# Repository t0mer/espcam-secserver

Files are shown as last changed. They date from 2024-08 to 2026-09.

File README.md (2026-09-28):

# ESP32-CAM Security Server




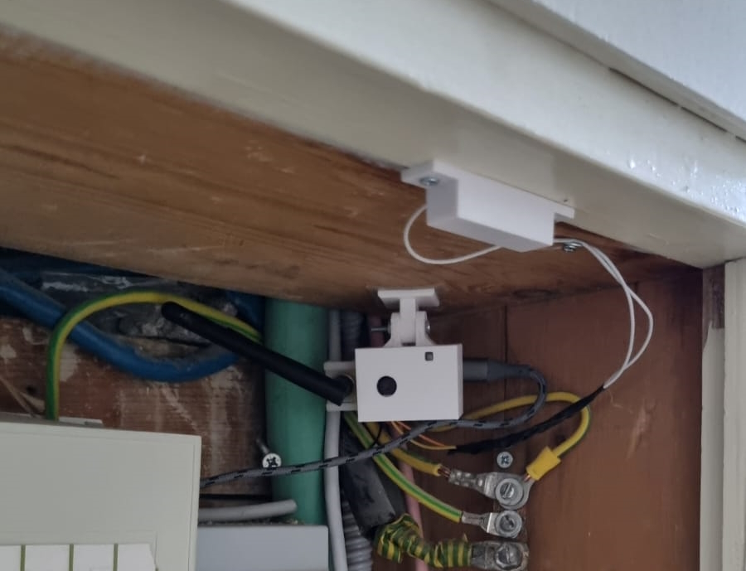
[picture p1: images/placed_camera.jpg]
Camera setup


## Overview

`espcam-secserver` is a DIY door security camera built from an ESP32-CAM and a small Python backend.
When a door magnet (reed switch) wired to the ESP32-CAM detects that the door opened, the camera
turns on its flash LED and calls the backend. The **FastAPI** backend then pulls three snapshots
from the camera, one second apart, and sends them to a WhatsApp contact or group through
[Green API](https://green-api.com/en).

The repository contains:

- `app/` - the FastAPI backend (runs in Docker).
- `CameraWebServer/` - the ESP32-CAM Arduino sketch (based on the Espressif `CameraWebServer`
  example, extended with the door sensor and backend trigger).
- `esp-32-cam-case-model_files/` - 3D-printable case files.
- `sequence-diagram/` - the flow diagram shown below.

## Table of Contents

- [Features](#features)
- [How it works](#how-it-works)
- [Hardware](#hardware)
- [Firmware setup](#firmware-setup)
- [Backend installation](#backend-installation)
- [Configuration](#configuration)
- [Green API setup](#green-api-setup)
- [API reference](#api-reference)
- [Security notes](#security-notes)
- [Troubleshooting](#troubleshooting)
- [Development](#development)
- [Contributing](#contributing)
- [License](#license)

## Features

- **Door-triggered capture**: a reed switch on GPIO 13 of the ESP32-CAM triggers the capture when
  the door opens.
- **Flash LED**: the on-board flash LED (GPIO 4) turns on when the door opens and turns off
  4 seconds after the door opens (or when the door closes), but not before the backend request
  returns, which can take up to `backendTimeoutMs` (10 s).
- **Three snapshots per event**: the backend fetches `/capture` from the camera three times,
  one second apart.
- **WhatsApp notifications**: each snapshot is uploaded and sent to a contact or group via
  [Green API](https://green-api.com/en), with an optional caption.
- **Multiple cameras**: the backend uses the caller's IP address as the camera address, so any
  number of cameras can share one backend.
- **Shared-secret authentication**: the trigger endpoint requires an `AUTH_TOKEN`, compared in
  constant time. The server refuses to start without it.
- **SSRF protection**: the backend only fetches images from callers on a private or loopback
  network.
- **Credential redaction**: the Green API token, instance ID and auth token are scrubbed from the
  application's log messages (Uvicorn's access log is not redacted).
- **Docker support**: slim Python 3.12 image, non-root user, built-in healthcheck on `/health`.
- **3D-printable case**: STL files for a wall-mounted case.

## How it works

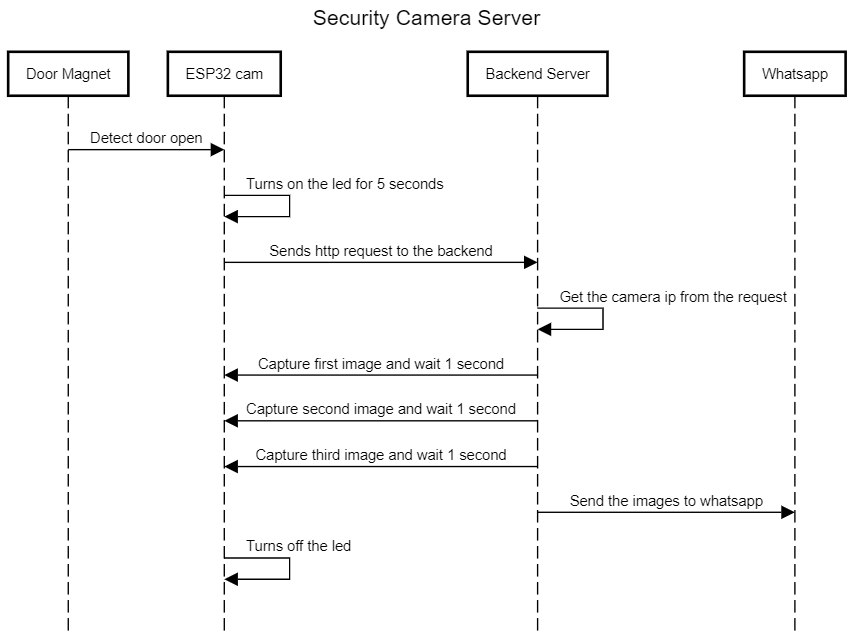
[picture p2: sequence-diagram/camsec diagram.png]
Sequence diagram


1. The door magnet opens and GPIO 13 on the ESP32-CAM reads `HIGH`.
2. The ESP32-CAM turns on the flash LED and sends `GET <backendUrl>` with an `X-Auth-Token` header.
3. The backend checks the token and takes the camera IP address from the request's source address.
4. The backend fetches `http://<camera-ip>/capture` three times, waiting one second after each.
5. Each captured image is uploaded to Green API and sent to `TARGET` with the `MESSAGE` caption.
6. The LED turns off 4 seconds after the door opens, or when the door closes, but only once the
   backend request has returned (the request blocks the firmware loop).

The diagram source is in [`sequence-diagram/camsec diagram.txt`](sequence-diagram/camsec%20diagram.txt)
(sequencediagram.org syntax). Note that it says the LED stays on for 5 seconds; the firmware uses
4 seconds (`ledDuration = 4000`).

## Hardware

- **ESP32-CAM, AI Thinker model** (the sketch selects `CAMERA_MODEL_AI_THINKER`; other boards are
  defined in `camera_pins.h` but require changing the `#define`).
- **USB-to-serial adapter** (FTDI or similar) to flash the ESP32-CAM, unless your board has a USB
  programmer base.
- **Door magnet / reed switch** between **GPIO 13** and **GND**. The pin uses the internal pull-up,
  so it reads `LOW` while the magnet holds the switch closed and `HIGH` when the door opens.
- **5 V power supply** for the ESP32-CAM.

### Case

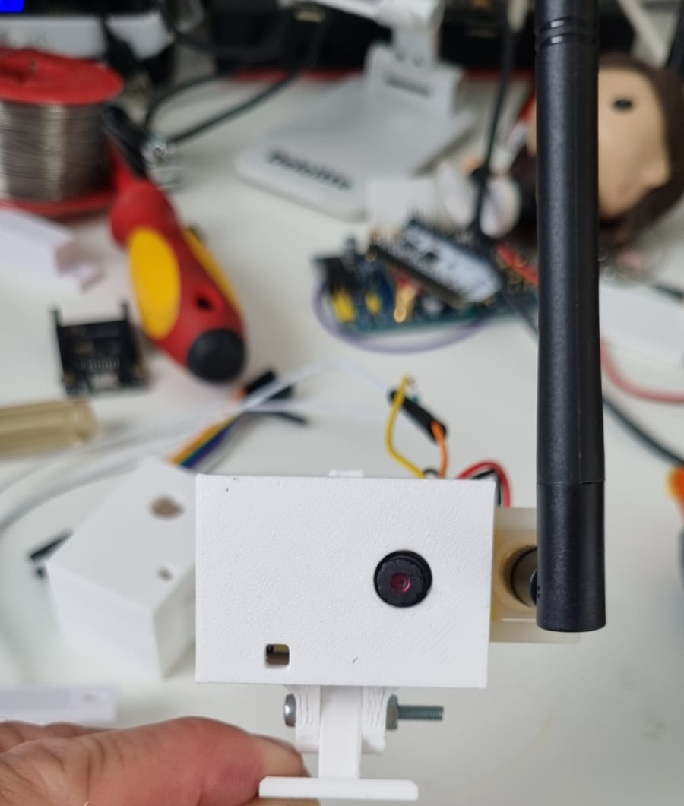
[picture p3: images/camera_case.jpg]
Camera case


The case is the [ESP 32 Cam Case](https://www.printables.com/model/30066-esp-32-cam-case) by
Fabian on Printables, released into the public domain. The files are in
[`esp-32-cam-case-model_files/`](esp-32-cam-case-model_files):

| File | Part |
|---|---|
| `gehause.stl` | Housing |
| `deckel.stl` | Lid |
| `fuss.stl` | Wall mount (foot) |

The model's print sheet (the PDF in the same folder) lists PLA, 0.20 mm layers, a 0.40 mm nozzle,
about 22 g of filament and about 2 hours on a Prusa MINI.

## Firmware setup

1. Install the [Arduino IDE](https://www.arduino.cc/en/software) and the **esp32** board package
   by Espressif (Boards Manager).
2. Open `CameraWebServer/CameraWebServer.ino`.
3. Edit the settings at the top of the sketch:

   | Setting | Description |
   |---------|-------------|
   | `ssid` / `password` | Your Wi-Fi network credentials. |
   | `backendUrl` | Base URL of the backend, including scheme, host and port, for example `http://192.168.1.100:8000/`. With the provided `docker-compose.yaml`, the host port is `80`. |
   | `authToken` | Must match the backend's `AUTH_TOKEN`. |
   | `backendTimeoutMs` | Timeout for the trigger request (default `10000` ms). |
   | `doorPin` | Reed switch GPIO (default `13`). |
   | `ledPin` | Flash LED GPIO (default `4`). |
   | `ledDuration` | Minimum time the LED stays on (default `4000` ms); it stays on until the backend request returns. |

4. Select the **AI Thinker ESP32-CAM** board and the serial port. The sketch folder contains a
   custom `partitions.csv`, which the esp32 Arduino core uses automatically.
5. Put the board in flashing mode (GPIO 0 to GND on most boards), upload, then remove the jumper
   and reset.
6. Open the Serial Monitor at **115200** baud. After connecting, the board prints its address
   (`Camera Ready! Use 'http://<ip>' to connect`).

The camera must be on the same private network as the backend. A DHCP reservation for the camera
is not required: the backend reads the camera IP from each request.

The firmware keeps the standard `CameraWebServer` web interface: the control page and `/capture`
on port 80, and the MJPEG stream on port 81 (`/stream`).

## Backend installation

> **Note:** the image on Docker Hub (`techblog/espcam-secserver:latest` and `:0.0.1`) was published
> in August 2024 and predates the current source (for example `AUTH_TOKEN`, `/health` and the
> non-root user). Until a new image is published, build the image locally as shown below.

### Docker Compose (recommended)

```bash
git clone https://github.com/t0mer/espcam-secserver.git
cd espcam-secserver
docker build -t techblog/espcam-secserver .
```

Fill in the environment variables in `docker-compose.yaml`:

```yaml
services:
  espcam-secserver:
    image: techblog/espcam-secserver
    container_name: espcam-secserver
    restart: always
    environment:
      - GREEN_API_INSTANCE_ID= #Green API Instance Id
      - GREEN_API_TOKEN= #Green API Token
      - TARGET= #Target phone number 972*********@c.us for contact or @g.us for group
      - MESSAGE= #Caption for the image sent
      - AUTH_TOKEN= #Shared secret required to trigger the capture endpoint
      - CORS_ORIGINS= #Optional comma-separated allowed CORS origins
    ports:
      - "80:8000"
```

Then start it:

```bash
docker compose up -d
```

The container listens on port `8000`; the compose file publishes it on host port `80`.

### Docker

```bash
docker run -d --name espcam-secserver --restart always \
  -p 8000:8000 \
  -e GREEN_API_INSTANCE_ID=<instance-id> \
  -e GREEN_API_TOKEN=<token> \
  -e TARGET=972XXXXXXXXX@c.us \
  -e MESSAGE="Door opened" \
  -e AUTH_TOKEN=<shared-secret> \
  techblog/espcam-secserver
```

### Run without Docker

```bash
pip install -r requirements.txt
export GREEN_API_INSTANCE_ID=... GREEN_API_TOKEN=... TARGET=... AUTH_TOKEN=...
python3 app/app.py
```

The Docker image uses Python 3.12.

## Configuration

All configuration is done with environment variables.

| Variable | Required | Default | Description |
|---|---|---|---|
| `GREEN_API_INSTANCE_ID` | Yes | - | Green API instance ID. |
| `GREEN_API_TOKEN` | Yes | - | Green API instance token. |
| `TARGET` | Yes | - | WhatsApp chat ID to send the images to: `<phone>@c.us` for a contact (international format, digits only, for example `972501234567@c.us`) or `<id>@g.us` for a group. The value is used as-is, so include the suffix. |
| `AUTH_TOKEN` | Yes | - | Shared secret the camera must send to trigger a capture. Must match `authToken` in the firmware. |
| `MESSAGE` | No | none | Caption sent with each image. |
| `CORS_ORIGINS` | No | empty (no cross-origin access) | Comma-separated list of allowed CORS origins (`GET` only, no credentials). |
| `REQUEST_TIMEOUT` | No | `10` | Timeout in seconds for each image request to the camera. |
| `PORT` | No | `8000` | Port the server listens on. Keep it at `8000` in Docker: the image's `EXPOSE`, `HEALTHCHECK` and the compose port mapping all use 8000. |

The server exits at startup with `Missing required environment variables: ...` if any required
variable is empty.

## Green API setup

1. Create an account at [green-api.com](https://green-api.com/en) and create an instance.
2. Link the instance to a WhatsApp account by scanning the QR code in the Green API console.
3. Copy the **idInstance** into `GREEN_API_INSTANCE_ID` and the **apiTokenInstance** into
   `GREEN_API_TOKEN`.
4. Set `TARGET` to the chat that should receive the images (see the table above).

The backend uses the [`whatsapp-api-client-python`](https://pypi.org/project/whatsapp-api-client-python/)
SDK: it uploads each image with `uploadFile` and sends it with `sendFileByUrl`.

## API reference

FastAPI also serves interactive documentation at `/docs` (Swagger UI) and `/redoc`, and the
schema at `/openapi.json`.

### `GET /` - trigger a capture

Called by the ESP32-CAM when the door opens.

Authentication: the `X-Auth-Token` header, or the `token` query parameter, must equal `AUTH_TOKEN`.

```bash
curl -H "X-Auth-Token: <shared-secret>" http://<backend>:8000/
```

The request must come from the camera itself: the backend fetches images from
`http://<caller-ip>/capture`.

| Status | Meaning |
|---|---|
| `200` `"OK"` | Request accepted and processed. Returned even if some or all captures or sends failed; check the logs. |
| `400` | The client address is missing or invalid. |
| `401` | Missing or wrong token. |
| `403` | The caller is not on a private network. |
| `503` | `AUTH_TOKEN` is not configured. |

### `GET /health` - health check

Returns `{"status": "ok", "version": "1.0.0"}`. Used by the Docker `HEALTHCHECK`.

## Security notes

- Always set a long, random `AUTH_TOKEN`. The same value is compiled into the firmware.
- Prefer the `X-Auth-Token` header (the firmware uses it). A token passed as `?token=` can end up in
  access logs.
- Traffic between the camera and the backend is plain HTTP. Keep both on a trusted LAN and do not
  expose the backend to the internet.
- The camera's own web server (control page, `/capture`, `/stream`) has no authentication. Anyone
  on the network can view the camera.
- The firmware stores the Wi-Fi password and `authToken` in the sketch source. Do not commit your
  filled-in copy.
- The backend only fetches from private or loopback addresses, and redacts Green API credentials
  and the auth token from its application log messages (not from Uvicorn's access log).

## Troubleshooting

- **Container exits at startup with `Missing required environment variables`**: set
  `GREEN_API_INSTANCE_ID`, `GREEN_API_TOKEN`, `TARGET` and `AUTH_TOKEN`.
- **`401 Unauthorized`**: `authToken` in the firmware does not match `AUTH_TOKEN`.
- **`403 Camera must be on a private network`**: the request reached the backend from a public
  address. The camera must call the backend directly over the LAN.
- **No images arrive / `Failed to fetch image` in the logs**: the backend fetches from the request's
  source address. If something between the camera and the backend changes that address (a reverse
  proxy, NAT, or a Docker setup that does not preserve the client IP), the backend asks the wrong
  host for images. Call the backend directly; if Docker hides the client IP, try host networking.
- **The camera's Serial Monitor shows a negative HTTP response code**: the backend only answers
  after it has captured and sent all images, which can take longer than `backendTimeoutMs`. The
  backend still finishes the job; increase `backendTimeoutMs` if you want a clean response code.
- **`Camera init failed`**: check the board model selected in the sketch and the camera ribbon
  cable.

## Development

```
app/app.py                     FastAPI backend (single file)
CameraWebServer/               ESP32-CAM Arduino sketch
esp-32-cam-case-model_files/   3D-printable case (STL + print sheet)
sequence-diagram/              Flow diagram (PNG + source)
images/                        README images
Dockerfile, docker-compose.yaml
VERSION                        Image version used by the Docker workflow
```

Run locally:

```bash
pip install -r requirements.txt
AUTH_TOKEN=dev GREEN_API_INSTANCE_ID=... GREEN_API_TOKEN=... TARGET=... python3 app/app.py
```

GitHub Actions workflows (in practice both run manually; `docker-image.yml` is also set to run after a "Create Release" workflow that does not exist in this repository):

- **Docker Build** (`docker-image.yml`): builds `linux/amd64` and `linux/arm64` images and pushes
  `techblog/espcam-secserver:latest` and `:<VERSION>` to Docker Hub.
- **Publish to GHCR** (`publish-ghcr.yml`): builds `linux/amd64`, `linux/arm64` and `linux/arm/v7`
  images and pushes them to `ghcr.io/t0mer/espcam-secserver`.
  <!-- TODO: verify - no public GHCR package exists yet -->

## Contributing

Issues and pull requests are welcome at
[github.com/t0mer/espcam-secserver](https://github.com/t0mer/espcam-secserver).

## License

This project is licensed under the [Apache License 2.0](LICENSE).

The case model is by Fabian on Printables and is in the public domain.

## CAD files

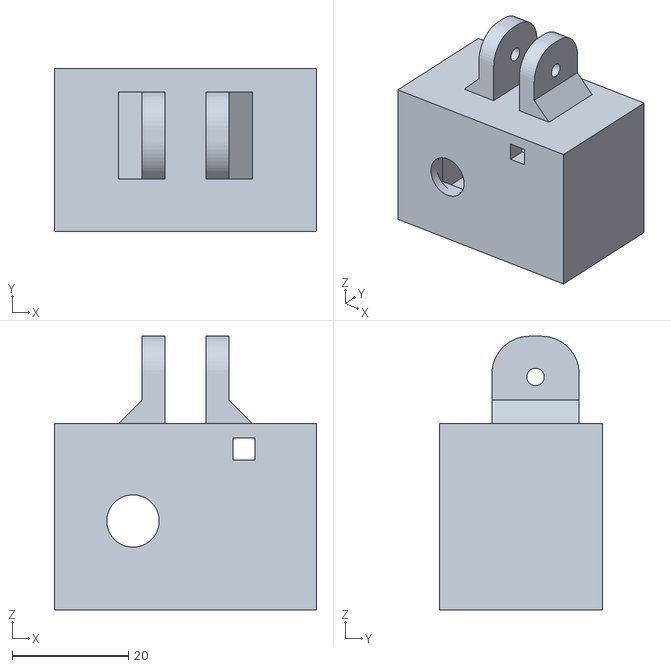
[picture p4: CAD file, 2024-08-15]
esp-32-cam-case-model_files/gehause.stl
45.0 x 28.0 x 47.0

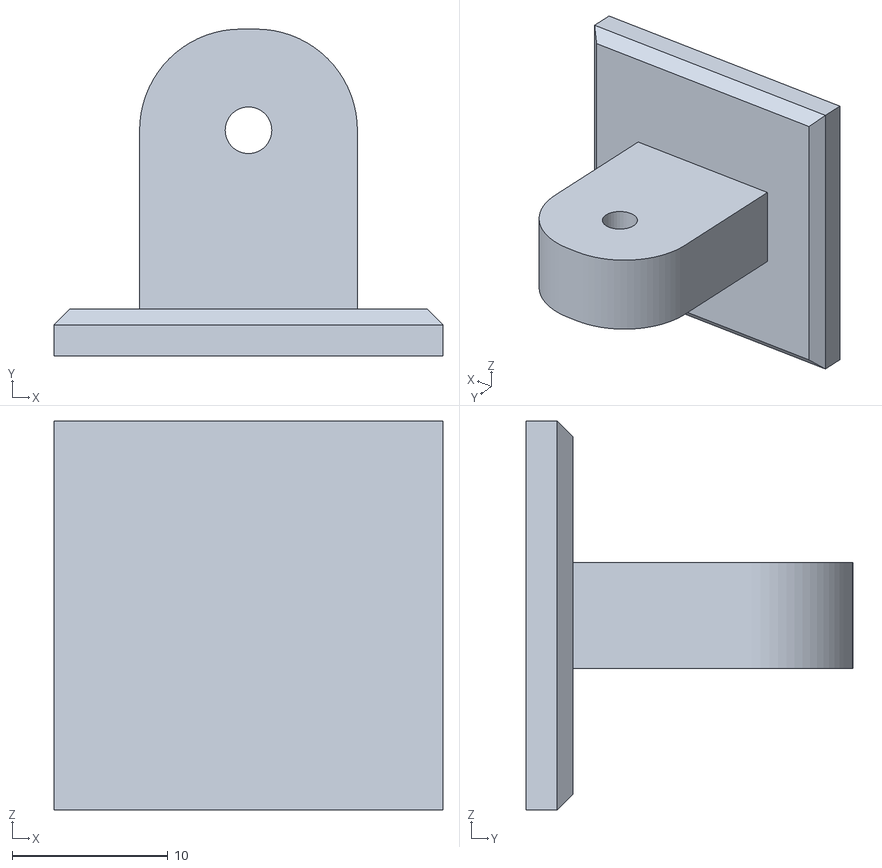
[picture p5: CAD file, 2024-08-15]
esp-32-cam-case-model_files/fuss.stl
25.0 x 21.0 x 25.0

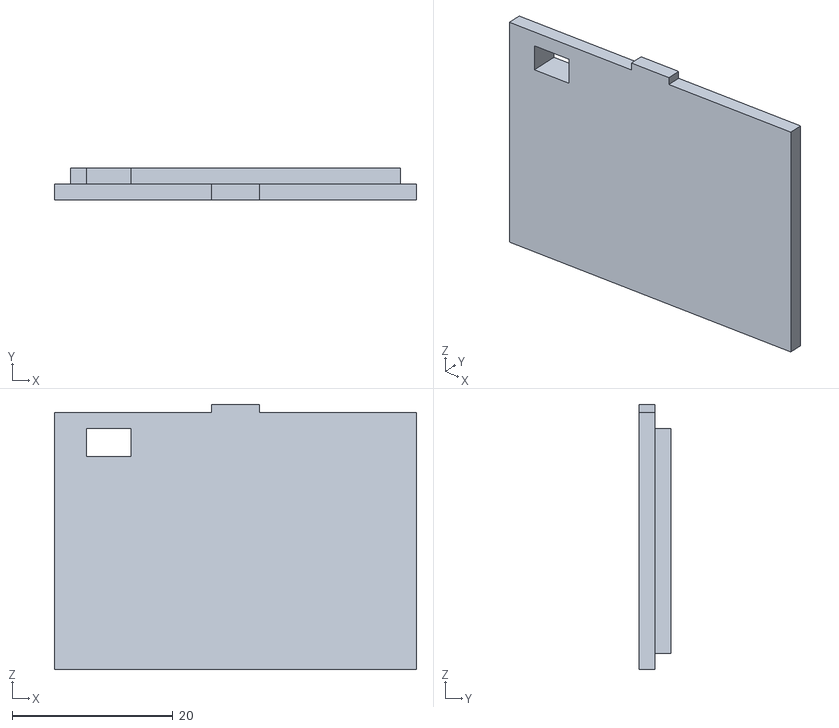
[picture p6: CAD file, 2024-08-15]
esp-32-cam-case-model_files/deckel.stl
45.0 x 4.00 x 33.0

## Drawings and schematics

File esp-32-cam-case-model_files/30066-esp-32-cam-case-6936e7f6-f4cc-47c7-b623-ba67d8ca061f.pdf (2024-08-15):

# ESP 32 Cam Case

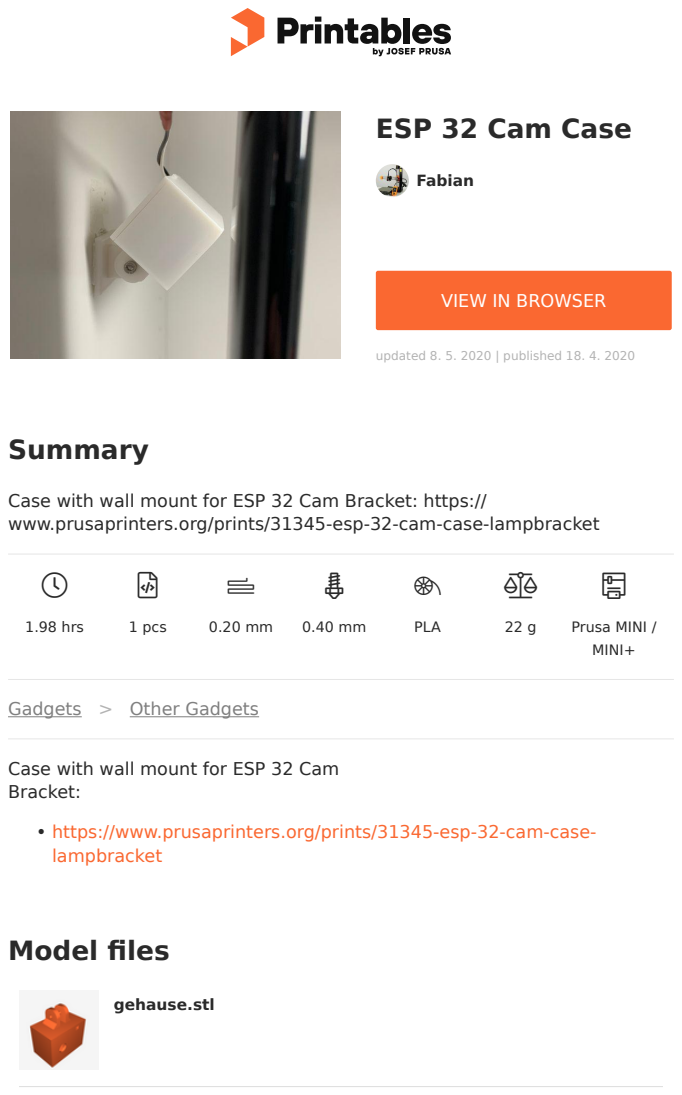
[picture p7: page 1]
1.98 hrs; 1 pcs; PLA; Prusa MINI /; MINI+; Model files; Summary; Gadgets; Other Gadgets; Fabian; updated 8. 5. 2020 | published 18. 4. 2020; gehause.stl

VIEW IN BROWSER (https://www.printables.com/model/30066-esp-32-cam-case)

Case with wall mount for ESP 32 Cam Bracket: https://
www.prusaprinters.org/prints/31345-esp-32-cam-case-lampbracket

Case with wall mount for ESP 32 Cam
Bracket:

https://www.prusaprinters.org/prints/31345-esp-32-cam-case-
lampbracket (https://www.prusaprinters.org/prints/31345-esp-32-cam-case-lampbracket)

# Print files

h PLA | k 0.40 mm | f 0.20 mm | 1.98 hrs | 22 g | d Prusa MINI / MINI+

# License

This work is licensed under a
Creative Commons (International License)

Public Domain (https://creativecommons.org/share-your-work/public-domain/cc0/)

✔ | Sharing without ATTRIBUTION
✔ | Remix Culture allowed
✔ | Commercial Use
✔ | Free Cultural Works
✔ | Meets Open Definition

deckel.stl

fuss.stl

esp_cam_02mm_pla_mini_1h59m.gcode

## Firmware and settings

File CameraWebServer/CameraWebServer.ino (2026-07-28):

#include "esp_camera.h"
#include <WiFi.h>
#include <HTTPClient.h>

// ===================
// Select camera model
// ===================
#define CAMERA_MODEL_AI_THINKER // Has PSRAM
#include "camera_pins.h"

// ===========================
// Enter your WiFi credentials
// ===========================
const char* ssid = "";
const char* password = "";

// ===========================
// Backend security server
// ===========================
// Base URL of the espcam-secserver instance (include scheme, host and port).
const char* backendUrl = "http://192.168.1.100:8000/";
// Must match the server's AUTH_TOKEN. The server rejects requests without it.
const char* authToken = "";
// Timeout (ms) for the outbound trigger request.
const uint16_t backendTimeoutMs = 10000;

// Additional hardware pins
const int doorPin = 13; // GPIO pin for door magnet
const int ledPin = 4; // Internal LED pin for ESP32-CAM

// Variables for door and LED control
bool isDoorOpen = false;
bool ledOn = false;
unsigned long doorOpenTime = 0;
const unsigned long ledDuration = 4000; // 4 seconds

void startCameraServer();
void setupLedFlash(int pin);

void setup() {
  Serial.begin(115200);
  Serial.setDebugOutput(true);
  Serial.println();

  // Setup for door magnet sensor and LED
  pinMode(doorPin, INPUT_PULLUP);
  pinMode(ledPin, OUTPUT);
  digitalWrite(ledPin, LOW); // Make sure LED is off initially

  camera_config_t config;
  config.ledc_channel = LEDC_CHANNEL_0;
  config.ledc_timer = LEDC_TIMER_0;
  config.pin_d0 = Y2_GPIO_NUM;
  config.pin_d1 = Y3_GPIO_NUM;
  config.pin_d2 = Y4_GPIO_NUM;
  config.pin_d3 = Y5_GPIO_NUM;
  config.pin_d4 = Y6_GPIO_NUM;
  config.pin_d5 = Y7_GPIO_NUM;
  config.pin_d6 = Y8_GPIO_NUM;
  config.pin_d7 = Y9_GPIO_NUM;
  config.pin_xclk = XCLK_GPIO_NUM;
  config.pin_pclk = PCLK_GPIO_NUM;
  config.pin_vsync = VSYNC_GPIO_NUM;
  config.pin_href = HREF_GPIO_NUM;
  config.pin_sccb_sda = SIOD_GPIO_NUM;
  config.pin_sccb_scl = SIOC_GPIO_NUM;
  config.pin_pwdn = PWDN_GPIO_NUM;
  config.pin_reset = RESET_GPIO_NUM;
  config.xclk_freq_hz = 20000000;
  config.frame_size = FRAMESIZE_HD;
  config.pixel_format = PIXFORMAT_JPEG; // for streaming
  config.grab_mode = CAMERA_GRAB_WHEN_EMPTY;
  config.fb_location = CAMERA_FB_IN_PSRAM;
  config.jpeg_quality = 12;
  config.fb_count = 1;
  
  if(config.pixel_format == PIXFORMAT_JPEG){
    if(psramFound()){
      config.jpeg_quality = 10;
      config.fb_count = 2;
      config.grab_mode = CAMERA_GRAB_LATEST;
    } else {
      config.frame_size = FRAMESIZE_HD;
      config.fb_location = CAMERA_FB_IN_DRAM;
    }
  } else {
    config.frame_size = FRAMESIZE_HD;
#if CONFIG_IDF_TARGET_ESP32S3
    config.fb_count = 2;
#endif
  }

  // camera init
  esp_err_t err = esp_camera_init(&config);
  if (err != ESP_OK) {
    Serial.printf("Camera init failed with error 0x%x", err);
    return;
  }

  sensor_t * s = esp_camera_sensor_get();
  if (s->id.PID == OV3660_PID) {
    s->set_vflip(s, 1); // flip it back
    s->set_brightness(s, 1); // up the brightness just a bit
    s->set_saturation(s, -2); // lower the saturation
  }
  if(config.pixel_format == PIXFORMAT_JPEG){
    s->set_framesize(s, FRAMESIZE_HD);
  }

#if defined(CAMERA_MODEL_M5STACK_WIDE) || defined(CAMERA_MODEL_M5STACK_ESP32CAM)
  s->set_vflip(s, 1);
  s->set_hmirror(s, 1);
#endif

#if defined(CAMERA_MODEL_ESP32S3_EYE)
  s->set_vflip(s, 1);
#endif

  WiFi.begin(ssid, password);
  WiFi.setSleep(false);

  while (WiFi.status() != WL_CONNECTED) {
    delay(500);
    Serial.print(".");
  }
  Serial.println("");
  Serial.println("WiFi connected");

  startCameraServer();

  Serial.print("Camera Ready! Use 'http://");
  Serial.print(WiFi.localIP());
  Serial.println("' to connect");
}

void loop() {
  // Check the door magnet sensor (assuming HIGH means door open)
  if (digitalRead(doorPin) == HIGH) { // Door is open
    if (!isDoorOpen) {
      isDoorOpen = true;
      doorOpenTime = millis();

      // Turn on LED at full brightness
      digitalWrite(ledPin, HIGH);
      ledOn = true;
      Serial.println("Door opened, LED on");

      // Notify the backend security server so it can capture and send images.
      if (WiFi.status() == WL_CONNECTED) {
        HTTPClient http;
        http.begin(backendUrl);
        http.addHeader("X-Auth-Token", authToken);
        http.setTimeout(backendTimeoutMs);
        int httpResponseCode = http.GET();
        Serial.printf("HTTP Response code: %d\n", httpResponseCode);
        http.end();
      }
    }
  } else { // Door is closed
    if (isDoorOpen) {
      isDoorOpen = false;
      Serial.println("Door closed");

      // Turn off LED when the door closes
      if (ledOn) {
        digitalWrite(ledPin, LOW);
        ledOn = false;
        Serial.println("LED off");
      }
    }
  }

  // Turn the LED off once, after it has been on for ledDuration.
  if (ledOn && millis() - doorOpenTime >= ledDuration) {
    digitalWrite(ledPin, LOW);
    ledOn = false;
    Serial.println("LED off");
  }

  delay(100); // Polling delay
}

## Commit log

2024-08-14 Add the CameraWebServer sketch files to the repo. close #4
    [partitions.csv]
2024-08-15 Adding images of the camera case and the placed camera
2024-08-15 Add the case model .stl files for 3D printing. close #5
    [deckel.stl, fuss.stl, gehause.stl]
2026-07-28 add timeout and network-error handling when fetching camera images
2026-07-28 pin direct dependencies and drop the ipaddress stdlib backport
2026-07-28 modernize docker workflow: current actions, GITHUB_OUTPUT, permissions
2026-07-28 wire door trigger to backend URL with auth token and timeout
2026-07-28 fix LED off logic to fire once and correct duration comment
    [CameraWebServer.ino]
